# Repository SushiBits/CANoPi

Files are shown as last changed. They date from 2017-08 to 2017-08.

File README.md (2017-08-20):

# SushiBits CANoPI

Isolated CAN or Raspberry Pi Zero

## Introduction & Goal

I have finally got around to take a jab at the CAN bus. This interface board
allows the CAN interface to be used by the Raspberry Pi Zero. It also provides
galvanic isolation for the CAN interface for added safety.

It also includes a real time clock for the Pi, as automated controllers often
calls for one.

## License

This is [open source hardware](http://www.oshwa.org/), licensed under the
[3-clause BSD license](LICENSE.md).

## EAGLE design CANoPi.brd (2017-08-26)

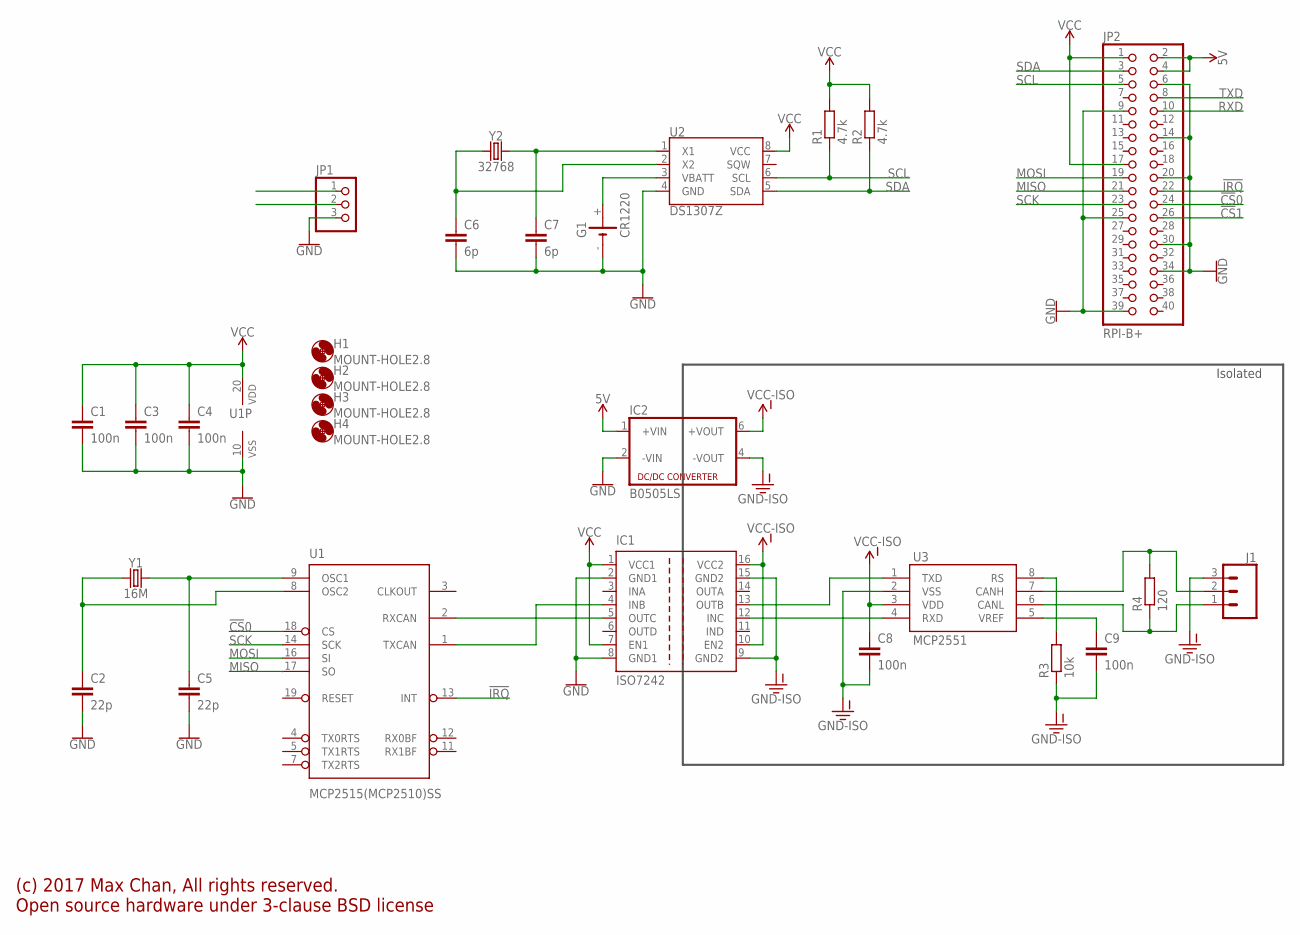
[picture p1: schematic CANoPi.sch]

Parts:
C1, C3, C4, C8, C9: 100n; C0603
C2, C5: 22p; C0603
C6, C7: 6p; C0603
G1: CR1220; CH291-1220LF
H1, H2, H3, H4: MOUNT-HOLE2.8; 2,8
IC1: ISO7242; SO-16DW
IC2: B0505LS; NMA-SINGLE
J1: CONN_03SCREW; SCREWTERMINAL-3.5MM-3
JP1: PINHD-1X3/90; 1X03/90
JP2: RPI-B+; 2X20
R1, R2: 4.7k; R0603
R3: 10k; R0603
R4: 120; R0603
U1: MCP2515(MCP2510)SS; SSOP20
U2: DS1307Z; SO08-0.15
U3: MCP2551; SO08
Y1: 16M; CRYSTAL-SMD-5X3.2-4PAD
Y2: 32768; CRYSTAL-SMD-3.2X1.5MM

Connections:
5V: IC2.1 (+VIN), JP2.2, JP2.4
!CS!0: JP2.24, U1.18 (CS)
!CS!1: JP2.26
!IRQ: JP2.22, U1.13 (INT)
CANH: J1.2, R4.2, U3.7 (CANH)
CANL: J1.1, R4.1, U3.6 (CANL)
CAN_OSC1: C5.1, U1.9 (OSC1), Y1.3 (2)
CAN_OSC2: C2.1, U1.8 (OSC2), Y1.1
CAN_RS: R3.2, U3.8 (RS)
CAN_VREF: C9.1, U3.5 (VREF)
GND: C1.2, C2.2, C3.2, C4.2, C5.2, C6.2, C7.2, G1.-, IC1.2 (GND1), IC1.8 (GND1), IC2.2 (-VIN), JP1.3, JP2.6, JP2.9, JP2.14, JP2.20, JP2.25, JP2.30, JP2.34, JP2.39, U1.10 (VSS), U2.4 (GND)
GND-ISO: C8.2, C9.2, IC1.9 (GND2), IC1.15 (GND2), IC2.4 (-VOUT), J1.3, R3.1, U3.2 (VSS)
MISO: JP2.21, U1.17 (SO)
MOSI: JP2.19, U1.16 (SI)
RTCX1: C7.1, U2.1 (X1), Y2.P$2 (2)
RTCX2: C6.1, U2.2 (X2), Y2.P$1 (1)
RXCAN: IC1.5 (OUTC), U1.2 (RXCAN)
RXD: JP1.1, JP2.10
RX_CAN: IC1.12 (INC), U3.4 (RXD)
SCK: JP2.23, U1.14 (SCK)
SCL: JP2.5, R1.1, U2.6 (SCL)
SDA: JP2.3, R2.1, U2.5 (SDA)
TXCAN: IC1.4 (INB), U1.1 (TXCAN)
TXD: JP1.2, JP2.8
TX_CAN: IC1.13 (OUTB), U3.1 (TXD)
VBATT: G1.+, U2.3 (VBATT)
VCC: C1.1, C3.1, C4.1, IC1.1 (VCC1), IC1.7 (EN1), JP2.1, JP2.17, R1.2, R2.2, U1.20 (VDD), U2.8 (VCC)
VCC-ISO: C8.1, IC1.10 (EN2), IC1.16 (VCC2), IC2.6 (+VOUT), U3.3 (VDD)

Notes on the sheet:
Isolated
(c) 2017 Max Chan, All rights reserved. Open source hardware under 3-clause BSD license

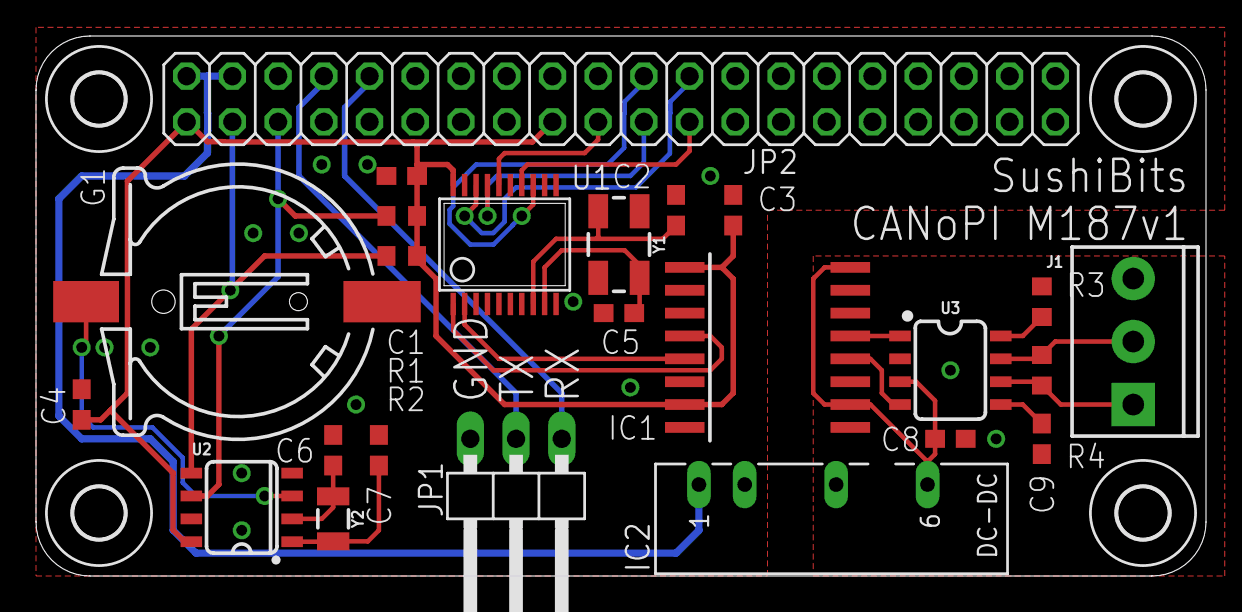
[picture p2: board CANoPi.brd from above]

Board: 2 copper layers, 65.0 x 30.0 mm, 28 parts (0 on the bottom side), 27 nets.

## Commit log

2017-08-20 Adding files to the project.
    [CANoPi.brd, CANoPi.sch]
2017-08-20 Added CANH and CANL markers
    [CANoPi.brd]
2017-08-26 Fixed the CAN GND pin issue
    [CANoPi.brd, CANoPi.sch]

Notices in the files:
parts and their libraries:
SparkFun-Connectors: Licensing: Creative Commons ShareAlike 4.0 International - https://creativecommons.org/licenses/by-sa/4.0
